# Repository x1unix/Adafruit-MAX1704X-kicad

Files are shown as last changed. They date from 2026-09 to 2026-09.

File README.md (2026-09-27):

# Adafruit MAX17048 LiPoly / LiIon Fuel Gauge — KiCad port

A **KiCad 10 conversion of Adafruit's original EagleCAD project** for the MAX17048
LiPoly / LiIon Fuel Gauge and Battery Monitor breakout (STEMMA QT form factor).

This repository contains **only the converted design**. It is not an Adafruit product
and is not maintained by Adafruit.

## Upstream

| | |
|---|---|
| Original project | <https://github.com/adafruit/Adafruit-MAX17048-PCB> |
| Product page | <https://www.adafruit.com/product/5580> |
| Converted from commit | `cc7d6e2` — *"Adding cookiecutter output"*, 2022-08-31 |
| Source format | EagleCAD 9.6.2 (`.sch` + `.brd`) |
| Designed by | Limor Fried / Ladyada for Adafruit Industries |

## Board

| | |
|---|---|
| Fuel gauge IC | **MAX17048G+T10** — TDFN-8, 2 x 2 mm, 0.5 mm pitch (package outline 21-0168) |
| Size | 25.40 x 20.32 mm (1.00 x 0.80 in) |
| Stackup | 2 layer |
| Interface | I2C, two STEMMA QT / Qwiic connectors (JST SH 4-pin) |
| Battery | Two JST PH 2-pin ports |
| Converted with | KiCad 10.0.5 |

`MAX17048G+T10` decodes as: `MAX17048` 1-cell ModelGauge fuel gauge, `G` TDFN package,
`+` lead-free, `T10` tape and reel. The I2C address is fixed at **`0x36`** (7-bit).

Datasheet: [`docs/max17048-max17049.pdf`](docs/max17048-max17049.pdf), with a condensed
markdown version at [`docs/max17048-datasheet.md`](docs/max17048-datasheet.md).

## Opening it

Open `Adafruit-MAX17048-STEMMA.kicad_pro` in KiCad 10.0.5 or newer.

Footprints are stored **inline in the `.kicad_pcb`**, and symbols live in the
project-local `Adafruit-MAX17048-STEMMA-eagle-import.kicad_sym`. There are no external
library dependencies — the project opens standalone.

## Deviations from upstream

One intentional change. Everything else is a faithful conversion.

- **MAX17048 symbol pin labels corrected.** Adafruit's Eagle symbol had `SCL` and `SDA`
  transposed, compensated by deliberately crossed net wiring. The labels now match the
  datasheet. **The netlist is byte-identical to upstream** — this is purely cosmetic.
  Full explanation: [`docs/max17048-symbol.md`](docs/max17048-symbol.md).

3D models were not inherited — the Eagle source contained none. The MAX17048 model has
since been added; the remaining parts still have empty 3D slots. See
[`docs/3d-models.md`](docs/3d-models.md).

## Documentation

| Document | Contents |
|---|---|
| [`docs/max17048-datasheet.md`](docs/max17048-datasheet.md) | Condensed MAX17048 datasheet — pinout, I2C address, registers, electrical limits |
| [`docs/conversion.md`](docs/conversion.md) | How the conversion was performed, and what the importer did or didn't carry over |
| [`docs/max17048-symbol.md`](docs/max17048-symbol.md) | The upstream SCL/SDA pin-label defect and why the board is still correct |
| [`docs/footprints.md`](docs/footprints.md) | Footprint provenance and the real manufacturer part behind each one |
| [`docs/3d-models.md`](docs/3d-models.md) | 3D model status, stock matches, and what needs downloading |
| [`docs/known-issues.md`](docs/known-issues.md) | DRC/ERC output, and which findings are false positives |

## License

The original design is released by Adafruit under
**Creative Commons Attribution-ShareAlike 3.0 Unported** — full text in
[`license.txt`](license.txt), copied verbatim from upstream. This conversion inherits
that license.

> Adafruit invests time and resources providing this open source design, please support
> Adafruit and open-source hardware by purchasing products from
> [Adafruit](https://www.adafruit.com)!
>
> Designed by Limor Fried/Ladyada for Adafruit Industries.
>
> Creative Commons Attribution/Share-Alike, all text above must be included in any
> redistribution.

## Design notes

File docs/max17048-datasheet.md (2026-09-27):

# MAX17048 — datasheet reference

Machine-readable condensation of [`max17048-max17049.pdf`](max17048-max17049.pdf)
(Maxim/Analog Devices doc `19-6171 Rev 7, 11/16`), scoped to what matters for this board.

**The PDF is authoritative.** This file exists so agents don't have to parse 19 pages of
images. Anything safety- or tolerance-critical should be confirmed against the PDF.

## Identity

| | |
|---|---|
| Part on this board | **MAX17048G+T10** |
| Function | 3µA 1-cell Li+ fuel gauge with ModelGauge |
| Package | 8 TDFN-EP, 2 x 2 mm, 0.5 mm pitch, 0.8 mm height |
| Package code | `T822+3` |
| Package outline | `21-0168` |
| Land pattern | `90-0065` |
| Temp range | -40°C to +85°C |
| Suffix decode | `G` = TDFN, `+` = lead-free/RoHS, `T10` = tape and reel |

`MAX17048` is the 1-cell part; `MAX17049` is the 2-cell variant sharing the same
datasheet, pinout and registers. **This board uses the 1-cell MAX17048.**

> Note: Adafruit's Eagle package description cites outline `21-0268`. The datasheet's
> Package Information table gives `21-0168` for 8 TDFN-EP. Use `21-0168`.

## Pinout — TDFN-8

```
[ 1 ] CTG      SDA [ 8 ]
[ 2 ] CELL     SCL [ 7 ]
[ 3 ] VDD    QSTRT [ 6 ]
[ 4 ] GND     ALRT [ 5 ]
              [ EP ]
```

| Pin | Name | Function |
|---|---|---|
| 1 | CTG | Connect to ground. |
| 2 | CELL | Connect to positive battery terminal. **MAX17048: not internally connected.** MAX17049: voltage sense input. |
| 3 | VDD | Power-supply input, bypass 0.1µF to GND. **MAX17048: this is the voltage sense input** — connect to positive battery terminal. |
| 4 | GND | Ground, connect to negative battery terminal. |
| 5 | ALRT | Open-drain, active-low alert output. Optionally to host interrupt. |
| 6 | QSTRT | Quick-start input, hardware reset. **Connect to GND if unused.** |
| 7 | SCL | I2C clock input. Internal pulldown for disconnect sensing. |
| 8 | SDA | Open-drain I2C data I/O. Internal pulldown for disconnect sensing. |
| — | EP | Exposed pad (TDFN only). Connect to GND. |

Note that on the **MAX17048**, `VDD` — not `CELL` — is what gets measured.

### As wired on this board

| Pin | Name | Net |
|---|---|---|
| 1 | CTG | `GND` |
| 2 | CELL | `VBAT` |
| 3 | VDD | `VDD` (fed via solder jumper SJ2) |
| 4 | GND | `GND` |
| 5 | ALRT | `INT` — broken out to JP1.5 |
| 6 | QSTRT | `QSTART` — broken out to JP1.6, **not tied to GND** |
| 7 | SCL | `SCL` |
| 8 | SDA | `SDA` |
| EP | — | `GND` |

Closest datasheet configuration (Table 3): *1S host-side location, low-cell interrupt*.

> The symbol in this project had `SCL`/`SDA` labels transposed upstream. Corrected —
> see [`max17048-symbol.md`](max17048-symbol.md) before touching anything I2C.

## I2C

| | |
|---|---|
| 7-bit address | **`0x36`** — fixed, not configurable |
| 8-bit address | `0x6C` write / `0x6D` read |
| Max clock | 400 kHz (works at any speed from 0) |
| Register width | **All registers are 16-bit.** 8-bit writes have no effect. |
| Byte order | MSB first; MSB of a 16-bit register lives at the even address |

Use `0x36` with Linux/Arduino/CircuitPython APIs, which take 7-bit addresses. The
datasheet quotes the 8-bit form, which is a common source of confusion.

Address auto-increments across a multi-byte transaction. Writes beyond `0x4F` are
ignored; reads beyond `0xFF` return `0xFF`.

## Registers

| Addr | Name | R/W | LSb | Default | Purpose |
|---|---|---|---|---|---|
| `0x02` | VCELL | R | 78.125 µV/cell | — | ADC measurement of VCELL |
| `0x04` | SOC | R | 1%/256 | — | Battery state of charge |
| `0x06` | MODE | W | — | `0x0000` | Quick-start, hibernate status, sleep enable |
| `0x08` | VERSION | R | — | `0x001_` | IC production version |
| `0x0A` | HIBRT | R/W | — | `0x8030` | Hibernate entry/exit thresholds |
| `0x0C` | CONFIG | R/W | — | `0x971C` | RCOMP, sleep, alert config |
| `0x14` | VALRT | R/W | 20 mV | `0x00FF` | Voltage alert min/max |
| `0x16` | CRATE | R | 0.208 %/hr | — | Approximate charge/discharge rate |
| `0x18` | VRESET/ID | R/W | 40 mV | `0x96__` | Reset threshold + factory ID |
| `0x1A` | STATUS | R/W | — | `0x01__` | Alert cause flags |
| `0x40`–`0x7F` | TABLE | W | — | — | Custom battery model |
| `0xFE` | CMD | R/W | — | `0xFFFF` | POR command |

### Bit layouts

**MODE (`0x06`)** — MSB: `X | QuickStart | EnSleep | HibStat | X X X X`, LSB all don't-care.

**CONFIG (`0x0C`)** — MSB `RCOMP[7:0]` (default `0x97`); LSB `SLEEP | ALSC | ALRT | ATHD[4:0]`.
- `RCOMP` — temperature compensation. Host should update at least once per minute:
  ```
  if (T > 20) RCOMP = 0x97 + (T - 20) * (-0.5);
  else        RCOMP = 0x97 + (T - 20) * (-5.0);
  ```
- `ATHD` — empty alert threshold, `(32 - ATHD)%`, range 1–32%. POR `0x1C` = 4%.
- `ALSC` — enable alert on 1% SOC change.
- `ALRT` — alert status; **write 0 to clear**, which also deasserts the ALRT pin.

**STATUS (`0x1A`)** — MSB `X | EnVR | SC | HD | VR | VL | VH | RI`.
`RI` reset indicator, `VH`/`VL` voltage high/low, `VR` voltage reset, `HD` SOC low,
`SC` 1% SOC change. Clear the bit after servicing.

**HIBRT (`0x0A`)** — MSB `HibThr` (0.208 %/hr), LSB `ActThr` (1.25 mV).
`0x0000` disables hibernate, `0xFFFF` forces it always on.

**VALRT (`0x14`)** — MSB `VALRT.MIN`, LSB `VALRT.MAX`, both 20 mV/LSb.

**VRESET/ID (`0x18`)** — MSB `VRESET[7:1]` (40 mV/LSb) + `Dis` bit 0; LSB is the
read-only factory `ID`. For removable batteries set at least 300 mV below empty
voltage; for captive batteries set to 2.5 V.

**CMD (`0xFE`)** — write `0x5400` for a full POR.

**TABLE unlock** — write `0x57` to `0x3F` and `0x4A` to `0x3E`. ModelGauge registers do
not update while unlocked, so relock promptly with `0x00` to both.

## Electrical

| Parameter | Min | Typ | Max | Unit |
|---|---|---|---|---|
| VDD supply voltage | 2.5 | | 4.5 | V |
| Supply current, sleep (TA ≤ +50°C) | | 0.5 | 2 | µA |
| Supply current, hibernate (reset comp disabled) | | 3 | 5 | µA |
| Supply current, hibernate (reset comp enabled) | | 4 | | µA |
| Supply current, active | | 23 | 40 | µA |
| Voltage error (VCELL 3.6 V, +25°C) | -7.5 | | +7.5 | mV/cell |
| Voltage-measurement resolution | | 1.25 | | mV/cell |
| Voltage-measurement range (MAX17048, VDD pin) | 2.5 | | 5 | V |
| VRESET configurable range (40 mV steps) | 2.28 | | 3.48 | V |
| VRESET trimmed at 3 V | 2.85 | 3.0 | 3.15 | V |
| ADC sample period, active | | 250 | | ms |
| ADC sample period, hibernate | | 45 | | s |
| SCL clock frequency | 0 | | 400 | kHz |
| VIH (SDA, SCL, QSTRT) | 1.4 | | | V |
| VIL (SDA, SCL, QSTRT) | | | 0.5 | V |
| VOL (SDA, ALRT) at IOL = 4 mA | | | 0.4 | V |
| Bus low-detection timeout | 1.75 | | 2.5 | s |

### Absolute maximum ratings

| | |
|---|---|
| CELL to GND | -0.3 V to +12 V |
| All other pins to GND | -0.3 V to +6 V |
| Continuous sink current, SDA / ALRT | 20 mA |
| Operating temperature | -40°C to +85°C |
| Storage temperature | -55°C to +125°C |
| Reflow soldering | +260°C |
| Lead temperature (TDFN, soldering 10s) | +300°C |

## Behaviour worth knowing

- **ModelGauge needs no current-sense resistor** and does not accumulate error the way
  coulomb counters do. No periodic correction events required.
- **Battery insertion:** OCV is ready 17 ms after insertion, SOC 175 ms after that.
  First SOC update is roughly 1 s after POR.
- **Quick-start should usually not be used.** The IC handles insertion transparently.
  Only use it when the power-up sequence is noisy enough to spoil the initial SOC
  estimate, and only when VCELL is fully relaxed. POR includes a quick-start.
- **Hibernate is automatic by default** and is the recommended configuration. The IC
  drops to a 45 s ADC period below C/4 loading, cutting quiescent current under 5 µA
  without hurting accuracy.
- **Sleep mode** (< 1 µA) halts everything — the IC cannot detect self-discharge, so
  wake it before charging or discharging. Enter with `MODE.EnSleep = 1` plus either
  `CONFIG.SLEEP = 1` or holding SDA and SCL low past `tSLEEP`. Prefer hibernate if
  4 µA is tolerable.
- **Alerts** are level-driven: ALRT stays low until software writes `CONFIG.ALRT = 0`.
  Five sources — low SOC, 1% SOC change, reset, overvoltage, undervoltage.
- **Instantaneous voltage does not map to SOC.** One VCELL value can correspond to many
  SOC values (3.81 V occurs at 2%, 50% and 72% in the datasheet example). Don't
  reimplement SOC from voltage.

## Pull-ups

The IC provides none. The system must supply pull-ups on SDA, SCL and ALRT (if used).
On this board that is the `RESPACK_4X0603` array (R3, 10K).

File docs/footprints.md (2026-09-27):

# Footprint provenance

All footprints are **Adafruit's originals**, carried over from the Eagle `.brd` and
stored inline in `Adafruit-MAX17048-STEMMA.kicad_pcb`.

**Do not swap these for KiCad-official footprints.** Adafruit's pads deliberately
differ — oversized JST mounting tabs, 0.9 mm outer pitch on the resistor array, longer
JST PH pin pads. Substituting stock footprints would change the board.

## Real parts behind each footprint

Identified by comparing pad geometry against the KiCad-official library. Eagle stores
pad rotation separately (`rot="R90"`), which has to be applied before comparing.

| Ref | Eagle footprint | Actual part | Match quality |
|---|---|---|---|
| X3 | `TDFN8_2X2MM` | **MAX17048G+T10**, TDFN-8 2x2 mm, 0.5 mm pitch, EP 0.8 x 1.38 mm (package outline 21-0168) | KiCad equivalent: `TDFN-8-1EP_2x2mm_P0.5mm_EP0.8x1.2mm` |
| CONN3, CONN4 | `JST_SH4` | **JST SM04B-SRSS-TB**, SH series 1.0 mm, 4-pin, side-entry SMT (STEMMA QT / Qwiic) | Exact match to KiCad-official: 0.6 x 1.55 pins at 1 mm pitch, 1.2 x 1.8 tabs |
| X1, X2 | `JSTPH2_BATT` | **JST S2B-PH-SM4-TB**, PH series 2.0 mm, 2-pin, side-entry SMT with tabs | Same part; Adafruit uses longer pin pads (4.6 vs 3.5 mm) and larger tabs |
| R3 | `RESPACK_4X0603` | 4 x 0603 convex resistor array, 10K | Near-match to `R_Array_Convex_4x0603`; Adafruit's outer pads sit at 0.9 mm, stock is 0.8 mm, and the array runs along X rather than Y |
| C1, C2 | `0603-NO` | 1uF 0603 MLCC | Standard 0603 |
| R2 | `0603-NO` | 10K 0603 | Standard 0603 |
| D1 | `CHIPLED_0603_NOOUTLINE` | Green 0603 LED | Standard 0603 |
| JP1 | `1X06_ROUND_70` | 1x6 2.54 mm THT header | 1 mm drill, 1.778 mm pad |
| JP2 | `1X02_ROUND` | 1x2 2.54 mm THT header | 1 mm drill, 1.778 mm pad |
| SJ1 | `SOLDERJUMPER_CLOSEDWIRE` | Solder jumper, normally closed | The `WIRE` pad intentionally bridges pads 1 and 2 |
| SJ2 | `SOLDERJUMPER_2WAY_OPEN_NOPASTE` | 3-pad 2-way solder jumper | |
| U$19, U$21 | `MOUNTINGHOLE_2.5_PLATED` | 2.5 mm plated mounting hole, 3.2 mm pad | |
| FID3, FID4 | `FIDUCIAL_1MM` | 1 mm fiducial | |
| U$22 | `ADAFRUIT_3.5MM` | Adafruit logo, silkscreen only | |
| U$25 | `PCBFEAT-REV-040` | Revision marker, silkscreen only (`${REV}` = 040) | |
| U$30, U$31 | `STEMMAQT` | STEMMA QT label, silkscreen only | |
| UNK_HOLE_0/1 | — | Eagle free holes, 2.54 mm NPTH — not components | |

## Connector pinouts

STEMMA QT / Qwiic (`JST_SH4`), matching the standard:

```
1 = GND    2 = V+ (VCC)    3 = SDA    4 = SCL
```

Both CONN3 and CONN4 are wired in parallel, as pass-through I2C ports.

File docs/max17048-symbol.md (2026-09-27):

# The MAX17048 SCL/SDA pin-label defect

**Summary: Adafruit's Eagle symbol labels SCL and SDA backwards, and the schematic
wiring compensates. The copper is correct. Do not "fix" this by rewiring.**

## The datasheet

`MAX17048G+T10`, TDFN-8 2 x 2 mm (package outline 21-0168):

```
[ 1 ] CTG      SDA [ 8 ]
[ 2 ] CELL     SCL [ 7 ]
[ 3 ] VDD    QSTRT [ 6 ]
[ 4 ] GND     ALRT [ 5 ]
                  [ EP ] thermal pad
```

Pin 7 is SCL. Pin 8 is SDA. (`docs/max17048-max17049.pdf`, Pin Configuration.)

## Error 1 — the symbol

In Adafruit's `adafruit_sensor` Eagle library, `MAX17048/T` maps pin *names* to pads
like this:

```
SCL   -> pad 8      (datasheet says pad 8 is SDA)
SDA   -> pad 7      (datasheet says pad 7 is SCL)
VDD   -> pad 3      CELL  -> pad 2
!ALRT -> pad 5      QSTRT -> pad 6
VSS   -> pads 1, 4, THERMAL
```

Both I2C labels are transposed.

## Error 2 — the wiring, which cancels it

The schematic then connects the nets to the *wrong-looking* pins, on purpose:

```
net SCL  ->  symbol pin "SDA"  ->  pad 7   = SCL   correct
net SDA  ->  symbol pin "SCL"  ->  pad 8   = SDA   correct
```

The Eagle board file confirms the signals land on the right copper:

```
net SDA -> CONN3.3, X3.8
net SCL -> CONN3.4, X3.7
```

That also matches the STEMMA QT / Qwiic standard (1 = GND, 2 = V+, 3 = SDA, 4 = SCL),
so the whole signal chain is sound. This is why the shipping product works.

## What was changed in this port

Only the two pin **names** on `MAX17048/T`, in both places KiCad stores a symbol:

- `Adafruit-MAX17048-STEMMA-eagle-import.kicad_sym` (the project library)
- the `lib_symbols` cache embedded in `Adafruit-MAX17048-STEMMA.kicad_sch`

Both are required — the schematic embeds its own copy of every symbol, and that copy is
what the canvas renders. Editing one alone leaves the two out of sync, which ERC reports
as `lib_symbol_issues`.

No wires were touched. Wires attach to pin positions and numbers, not names, so net
`SCL` stayed on pin 7 and simply reads correctly now. The `.kicad_pcb` was not modified.

### Verification

Exporting the full `(ref, pin)` mapping for every net before and after gave an
identical result:

```
FULL netlist identical before vs after?  YES - electrically unchanged
```

Resulting X3 assignment, every pin matching the datasheet:

```
net SCL    -> pin 7        name=SCL_7         datasheet=SCL
net SDA    -> pin 8        name=SDA_8         datasheet=SDA
net VDD    -> pin 3        name=VDD_3         datasheet=VDD
net VBAT   -> pin 2        name=CELL_2        datasheet=CELL
net INT    -> pin 5        name=~{ALRT}_5     datasheet=ALRT
net QSTART -> pin 6        name=QSTRT_6       datasheet=QSTRT
net GND    -> pins 1, 4, THERMAL              CTG + GND + EP
```

Reproduce with:

```sh
kicad-cli sch export netlist --format kicadxml \
  -o /tmp/net.xml Adafruit-MAX17048-STEMMA.kicad_sch
```

## Related non-issues

- **There is no `CTG` pin on the symbol.** The datasheet defines pin 1 as CTG,
  "connect to ground", so Adafruit folded it into `VSS`.
- **`VSS` shows no single pin number** because it carries three pads — 1, 4 and
  THERMAL. KiCad imports that as stacked pins; all three are present in the netlist.

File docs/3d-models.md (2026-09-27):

# 3D models

**Status: 1 of 9 attached.** X3 (the MAX17048) has a model; the rest still have empty
3D slots.

This is deliberate, not an oversight. The Eagle source contains **zero 3D data** — no
`<package3d>` elements, no `packages3d` section, no STEP references. Eagle 9.6.2 kept
3D packages in Autodesk-managed cloud libraries, and Adafruit's published files carry
only `urn:adsk.eagle:` handles for two symbols. Nothing was lost in conversion; there
was nothing to inherit.

Models can be attached at any time without redoing the import.

## Attached

### X3 — MAX17048G+T10

`3dmodels/MAX17048G-T10--3DModel-STEP-510211.STEP` — AP214 STEP exported from
SolidWorks 2021, internally named `MAX17048G+T10.STEP`. Geometry verified at
2.000 x 2.000 x 0.800 mm, matching the TDFN-8 2 x 2 mm body.

Attached to the `TDFN8_2X2MM` footprint in `Adafruit-MAX17048-STEMMA.kicad_pcb` as:

```
(model "${KIPRJMOD}/3dmodels/MAX17048G-T10--3DModel-STEP-510211.STEP"
    (offset (xyz 0 0 0))
    (scale  (xyz 1 1 1))
    (rotate (xyz -90 0 0))
)
```

**The -90 degree X rotation is required.** The source model is authored **Y-up** — the
2 x 2 mm body lies in the X-Z plane with height running along +Y from 0 to 0.8 mm.
KiCad expects Z-up, with the part sitting on the board at Z = 0. Models exported from
SolidWorks and 3D ContentCentral commonly have this convention; check the axis extents
before assuming a model drops in at zero rotation.

Verified by rendering: body centred in the silkscreen outline, all 8 leads landing on
their pads, pin-1 dot over pad 1.

```sh
kicad-cli pcb render --side top --zoom 3.4 --pivot '0,-0.165,0' \
  --quality high -o /tmp/x3.png Adafruit-MAX17048-STEMMA.kicad_pcb
```

## Where to put them

Project-local, so they survive KiCad upgrades and travel with the repository:

```
3dmodels/
```

Reference them from each footprint's 3D tab as:

```
${KIPRJMOD}/3dmodels/<file>.step
```

## Still needs downloading — 1 part

Ships with a KiCad **footprint** but no STEP file. Verified absent across all 7245
stock models in KiCad 10.0.5.

### X1, X2 — JST S2B-PH-SM4-TB

PH series, 2 mm pitch, 2-pin, side-entry SMT with mounting tabs.
KiCad ships `JST_PH_S2B-PH-SM4-TB_1x02-1MP_P2.00mm_Horizontal.kicad_mod` but not the
`.step`. Only the through-hole variants have models (`B2B-PH-K`, `S2B-PH-K`).

- [SnapMagic Search](https://www.snapeda.com/parts/S2B-PH-SM4-TB/JST%20Sales%20America%20Inc./view-part/)
- [Ultra Librarian](https://app.ultralibrarian.com/details/c0ea14ac-1ee6-11e9-ab3a-0a3560a4cccc/JST/S2B-PH-SM4-TB-LF-SN-)
- [Digi-Key](https://www.digikey.com/en/models/926655)
- [3D ContentCentral](https://www.3dcontentcentral.com/download-model.aspx?catalogid=171&id=817113)

## Available in stock — 7 parts

Paths relative to `${KICAD10_3DMODEL_DIR}`.

| Ref | Model | Fit |
|---|---|---|
| C1, C2 | `Capacitor_SMD.3dshapes/C_0603_1608Metric.step` | exact |
| R2 | `Resistor_SMD.3dshapes/R_0603_1608Metric.step` | exact |
| D1 | `LED_SMD.3dshapes/LED_0603_1608Metric.step` | exact |
| JP1 | `Connector_PinHeader_2.54mm.3dshapes/PinHeader_1x06_P2.54mm_Vertical.step` | exact |
| JP2 | `Connector_PinHeader_2.54mm.3dshapes/PinHeader_1x02_P2.54mm_Vertical.step` | exact |
| CONN3, CONN4 | `Connector_JST.3dshapes/JST_SH_SM04B-SRSS-TB_1x04-1MP_P1.00mm_Horizontal.step` | pad geometry identical to KiCad-official, but the footprint origin differs by ~0.5 mm in Y — nudge in the 3D viewer |
| R3 | `Resistor_SMD.3dshapes/R_Array_Convex_4x0603.step` | approximate — needs a **90 degree Z rotation** (Adafruit's array runs along X, the model along Y), and Adafruit's outer pads are 0.9 mm vs the model's 0.8 mm |

For an exact R3, download a 4x0603 array model (Panasonic EXB-38V, Yageo YC164) instead.

## Needs no model

Mechanical or artwork only: `SJ1`, `SJ2` (solder jumpers, copper only), `FID3`, `FID4`
(fiducials), `U$19`, `U$21` (bare plated mounting holes), `U$22` (Adafruit logo),
`U$25` (rev marker), `U$30`, `U$31` (STEMMA QT silkscreen), `UNK_HOLE_0/1` (free holes).

## Note on sourcing

There is **no official Adafruit KiCad library** — Adafruit publishes Eagle libraries
only. Don't spend time looking for one.

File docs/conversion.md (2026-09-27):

# How this conversion was performed

Source: Adafruit's EagleCAD 9.6.2 project, commit `cc7d6e2` (2022-08-31).
Target: KiCad 10.0.5.

## Why the GUI was required

KiCad exposes its **board** importers to the command line but not its **schematic**
importers:

- `kicad-cli pcb import` — converts Eagle / Altium / PADS / CADSTAR / pcad boards headlessly.
- `kicad-cli sch` — offers only `erc`, `export`, `upgrade`. There is **no** `import`.

There is no standalone `eeschema` binary on macOS either; the editors ship as separate
`.app` bundles with no CLI entry point.

So the schematic had to go through the GUI, and doing the whole project there is
preferable anyway — a full project import links symbols to footprints, so the board
netlist is cross-referenced to the schematic. A CLI board-only import gives you nets
but no schematic association.

```
File -> Import Non-KiCad Project -> Import EAGLE Project...
```

Select the `.sch`; the matching `.brd` is picked up automatically from the same
basename and folder.

## What carried over cleanly

Eagle `.sch`/`.brd` files are **self-contained** — every footprint and symbol
definition is embedded in the file itself. All 16 packages used by the board were
present, with zero used-but-undefined packages, so no external library had to be
installed before converting.

Import statistics:

| | |
|---|---|
| Footprints | 24 |
| Tracks | 126 |
| Vias | 13 |
| Zones | 6 |
| Pads | 65 |
| Nets | 11 — GND, VCC, VDD, VBAT, SCL, SDA, INT, QSTART, N$1, N$2, N$4 |

Footprints are written **inline into the `.kicad_pcb`**, so the geometry is Adafruit's
original and the board needs no `fp-lib-table`. Symbols went into the project-local
`Adafruit-MAX17048-STEMMA-eagle-import.kicad_sym`, registered via `sym-lib-table`.

## What did not carry over

- **Design rules and net classes.** Board Setup starts at KiCad defaults. Upstream used
  looser clearances than KiCad's defaults — see [`known-issues.md`](known-issues.md).
- **3D models.** The Eagle project contained none to begin with. See
  [`3d-models.md`](3d-models.md).
- **Eagle-specific layers** needed review: `tRestrict`/`bRestrict`, `tKeepout`,
  `tGlue`, `Measures`, `tDocu`. The GUI importer resolved these; a raw
  `kicad-cli pcb import` instead leaves items on an `UNDEFINED` layer, which makes the
  board unloadable until remapped (`Measures` dimensions belong on `Dwgs.User`,
  keepout graphics on a `User.n` layer).

## Import artifacts

- **`UNK_HOLE_0` / `UNK_HOLE_1`** at (2.54, 17.78) and (22.86, 17.78) are Eagle *free
  holes* (`<hole drill="2.54">`), not components. The importer wraps each bare NPTH in
  a dummy footprint, so they appear as unannotated parts.
- **`${REV}` text variable** on the `PCBFEAT-REV-040` rev marker (U$25) is unresolved
  unless defined. It is set to `040` in `Adafruit-MAX17048-STEMMA.kicad_pro`, taken
  from the Eagle package name.

## Verification commands

```sh
# board loads, and DRC
kicad-cli pcb drc --format json -o /tmp/drc.json Adafruit-MAX17048-STEMMA.kicad_pcb

# schematic ERC
kicad-cli sch erc --format json -o /tmp/erc.json Adafruit-MAX17048-STEMMA.kicad_sch

# netlist, for comparing against the Eagle source
kicad-cli sch export netlist --format kicadxml -o /tmp/net.xml Adafruit-MAX17048-STEMMA.kicad_sch

# visual check
kicad-cli pcb render --side top -o /tmp/top.png Adafruit-MAX17048-STEMMA.kicad_pcb

# symbol library parses
kicad-cli sym export svg -o /tmp/syms Adafruit-MAX17048-STEMMA-eagle-import.kicad_sym
```

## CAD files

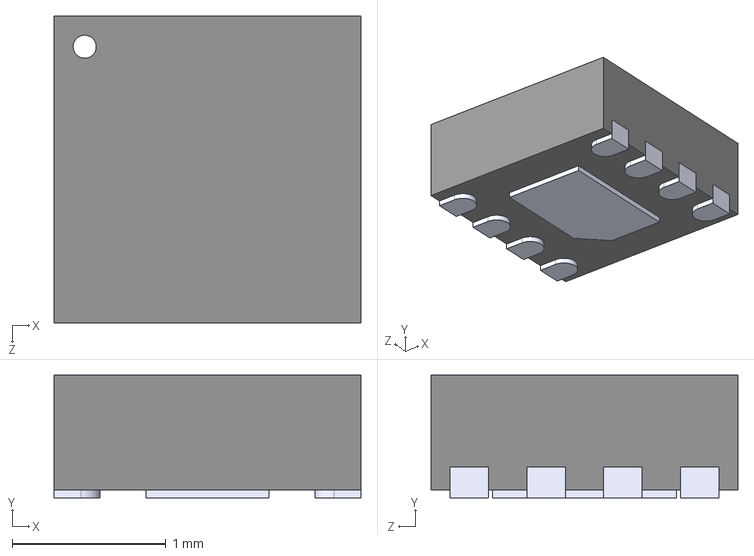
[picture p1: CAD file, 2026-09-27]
3dmodels/MAX17048G-T10--3DModel-STEP-510211.STEP
2.00 x 0.8 x 2.00 mm

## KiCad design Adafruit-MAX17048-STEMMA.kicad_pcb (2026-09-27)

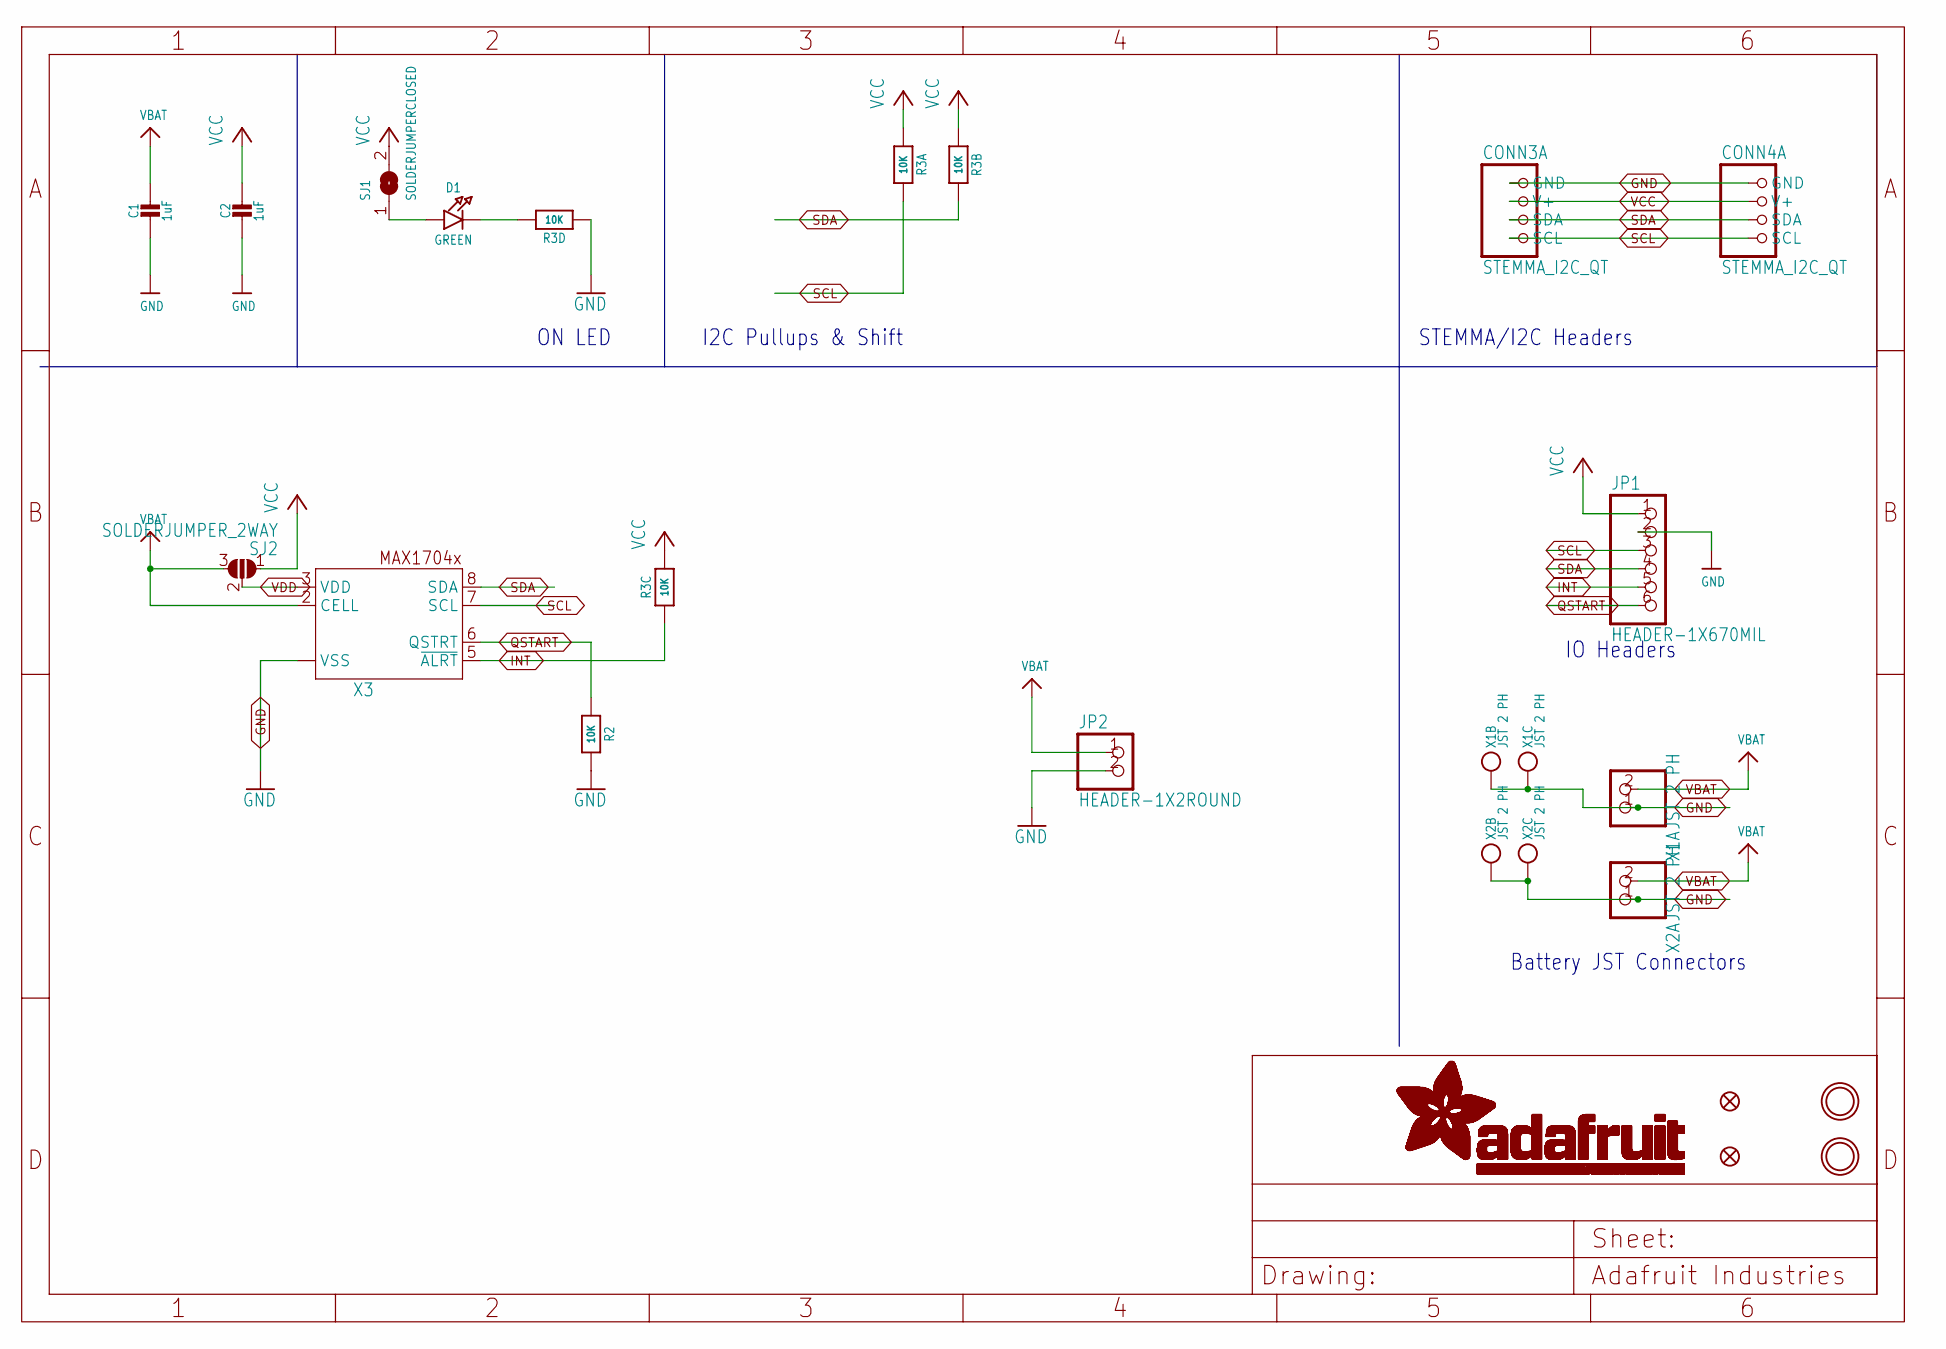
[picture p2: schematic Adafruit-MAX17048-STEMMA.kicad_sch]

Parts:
C1, C2: 1uF; 0603-NO
CONN3, CONN4: STEMMA_I2C_QT; JST_SH4
D1: GREEN; CHIPLED_0603_NOOUTLINE
FID3, FID4: FIDUCIAL_1MM
JP1: HEADER-1X670MIL; 1X06_ROUND_70
JP2: HEADER-1X2ROUND; 1X02_ROUND
R2: 10K; 0603-NO
R3: 10K; RESPACK_4X0603
SJ1: SOLDERJUMPERCLOSED; SOLDERJUMPER_CLOSEDWIRE
SJ2: SOLDERJUMPER_2WAY; SOLDERJUMPER_2WAY_OPEN_NOPASTE
U$19, U$21: MOUNTINGHOLE2.5; MOUNTINGHOLE_2.5_PLATED
X1, X2: JST 2 PH; JSTPH2_BATT
X3: MAX17048/T; TDFN8_2X2MM

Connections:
GND: C1.2, C2.2, CONN3.1 (GND), CONN4.1 (GND), JP1.2, JP2.2, R2.2, R3.4 (1), X1.1, X1.NC1, X1.NC2, X2.1, X2.NC1, X2.NC2, X3.1 (VSS), X3.4 (VSS), X3.THERMAL (VSS)
INT: JP1.5, R3.3 (1), X3.5 (~ALRT)
unnamed: D1.C, R3.5 (2)
unnamed: D1.A, SJ1.1
QSTART: JP1.6, R2.1, X3.6 (QSTRT)
SCL: CONN3.4 (SCL), CONN4.4 (SCL), JP1.3, R3.8 (2), X3.7 (SCL)
SDA: CONN3.3 (SDA), CONN4.3 (SDA), JP1.4, R3.7 (2), X3.8 (SDA)
VBAT: C1.1, JP2.1, SJ2.3, X1.2, X2.2, X3.2 (CELL)
VCC: C2.1, CONN3.2 (V+), CONN4.2 (V+), JP1.1, R3.1, R3.2 (1), R3.6 (2), SJ1.2, SJ2.1
VDD: SJ2.2, X3.3 (VDD)

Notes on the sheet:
I2C Pullups & Shift
STEMMA/I2C Headers
ON LED
IO Headers
Battery JST Connectors

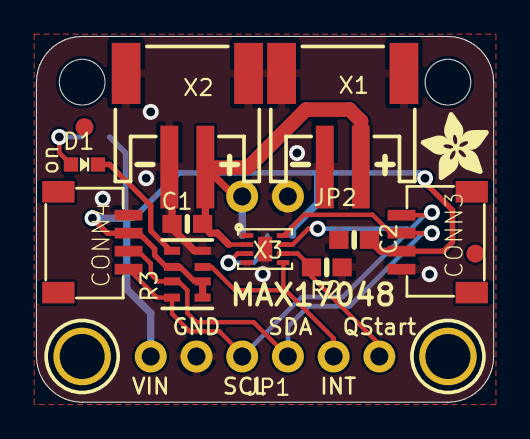
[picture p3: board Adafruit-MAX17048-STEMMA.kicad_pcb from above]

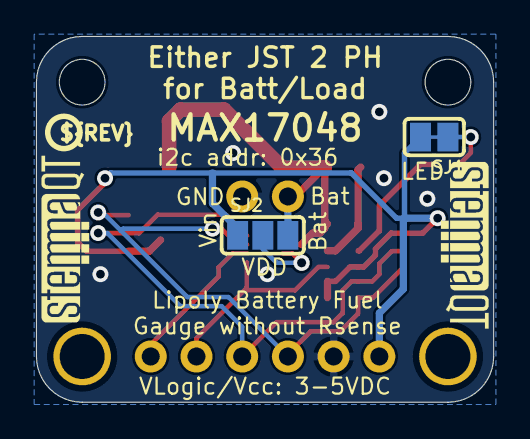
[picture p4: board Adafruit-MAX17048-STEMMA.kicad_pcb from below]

Board: 2 copper layers, 25.4 x 20.3 mm, 24 parts (5 on the bottom side), 10 nets.

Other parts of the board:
U$22: ADAFRUIT_3.5MM
U$25: PCBFEAT-REV-040
U$30, U$31: STEMMAQT
UNK_HOLE_0: dummyfp0
UNK_HOLE_1: dummyfp1

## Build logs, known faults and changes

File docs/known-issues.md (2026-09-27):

# Known issues and false positives

Both DRC and ERC report violations on this design. **Most are artifacts of the
conversion or of upstream design choices, not defects.** This document separates them
so nobody "fixes" a working board.

## DRC — 96 violations, 1 unconnected

Measured on the GUI-imported board with zones filled and KiCad default rules.

### Not bugs

| Finding | Count | Why |
|---|---|---|
| `silk_overlap`, `silk_over_copper` | 68 | Eagle tolerated silkscreen over pads; KiCad's defaults do not. Upstream shipped this way. |
| `solder_mask_bridge` | 18 | Fine-pitch parts against KiCad's default mask rules. |
| `clearance` on SJ1 (pad 1 / WIRE, pad 2 / WIRE) | 2 | **The solder jumper working as designed.** `SOLDERJUMPER_CLOSEDWIRE` has a netless `WIRE` pad that deliberately bridges pads 1 and 2 — that is what makes it normally-closed. See *Solder jumpers* below. |
| `items_not_allowed` | 2 | The mounting-hole pads sitting inside their own imported keepout. |
| `text_thickness`, `text_height` | 4 | Silkscreen text below KiCad's default minimums. |

### Worth attention

- **1 unconnected: an isolated GND island on F.Cu.** The top-layer GND pour fills as
  three islands. Two are properly stitched; the third (~2.33 mm², roughly
  X 150.4–154.6, Y 105.1–107.2, between X3 and CONN3) contains **no GND via and no GND
  pad**, so it is floating copper.

  **A stitching via does not fit.** The island is 4.21 x 2.09 mm but narrow — the
  largest via pad that clears all neighbouring copper by the board minimum (0.2032 mm)
  is **0.496 mm diameter**, at (151.06, 106.36). The board's standard via is 0.889 mm
  pad / 0.4826 mm drill, and even a 0.5 mm pad / 0.25 mm drill fails. A via small enough
  would need a sub-0.2 mm drill. Don't retry this.

  Remaining options: leave it (harmless floating copper at this size and frequency),
  set the zone's island-removal threshold so KiCad drops sub-area islands on refill, or
  move R2 / reroute to open up room — which changes Adafruit's layout.

- **2 `starved_thermal`.** JP2 pad 2 (GND, B.Cu) and X3 pad 4 (GND, F.Cu) each get one
  thermal spoke where KiCad's default rule wants two. Upstream had no such rule. X3's
  exposed pad is also tied to GND, so that one is immaterial.

- **Design rules and net classes did not carry over.** Board Setup is at KiCad defaults,
  which are *stricter* than what this board was manufactured to. Set real trace/via/
  clearance minimums before using DRC output to judge the layout.

### Fixed

- **Orphan `N$4` copper stub — removed.** In the Eagle source, signal `N$4` had **zero
  contactrefs** and exactly one wire segment: a 0.635 mm dangling stub on B.Cu that
  overlapped SJ2's pad 2 (`VDD`) and ran within 0.076 mm of the `VBAT` trace. It was
  stray copper inherited from upstream, not intentional design. Deleting it cleared the
  `shorting_items` violation and 2 `clearance` violations (4 -> 2, leaving only the two
  SJ1 solder-jumper ones). Total went 106 -> 96; `solder_mask_bridge` also moved 25 ->
  18 in the same edit, which is reproducible but not fully explained — the cleared
  pairs name SJ1/SJ2 mask polygons rather than `N$4` itself.

### Zone fill

Zones must be filled before DRC output means anything. Filling took unconnected items
from 20 to 1 and cleared all 6 `via_dangling` findings. If a checkout shows them
unfilled, press `B` in the PCB editor and re-run DRC before reading anything into the
counts above.

## Solder jumpers

KiCad models solder jumpers perfectly well — it ships 30 footprints in `Jumper.pretty`
(including `SolderJumper-2_P1.3mm_Bridged_*`) and 11 symbols in `Jumper.kicad_sym`
(`SolderJumper_2_Bridged`, `SolderJumper_3_Bridged12`, …). The everyday idiom is the
same as a **0 ohm resistor**: a two-pin part bridging two nets.

The difference is how the bridge is drawn. KiCad's bridged jumpers have **only two
pads** and no copper between them — the short is a solder blob the assembler adds, so
nothing overlaps and DRC stays quiet. Adafruit's Eagle footprint instead adds a **third
netless `WIRE` pad** physically overlapping pads 1 and 2, which KiCad reads as two
zero-clearance violations.

So the noise is a property of *this imported footprint*, not a gap in KiCad. Options:

1. **Leave it.** The violations are cosmetic; the board is correct.
2. **Give the `WIRE` pad a net** so it stops being a foreign object between two pads.
3. **Rebuild SJ1 as a KiCad solder jumper** (`SolderJumper_2_Bridged` +
   `SolderJumper-2_P1.3mm_Bridged_*`) or a 0 ohm resistor. Cleanest long term, but it
   replaces Adafruit's footprint — see [`footprints.md`](footprints.md) before doing it.

## ERC — 39 violations

| Finding | Count | Why |
|---|---|---|
| `footprint_link_issues` | 25 | Symbols' footprint fields don't resolve to a library, because footprints live **inline in the `.kicad_pcb`** and there is no `fp-lib-table`. Harmless unless you want "update PCB from schematic" to work. |
| `power_pin_not_driven` | 4 | No `PWR_FLAG` symbols. Normal for an imported schematic. |
| `unconnected_wire_endpoint` | 6 | Import artifacts. |
| `missing_bidi_pin`, `missing_unit` | 4 | Import artifacts. |

`lib_symbol_issues` should read **0**. A non-zero count means the project
`.kicad_sym` and the `lib_symbols` cache inside the `.kicad_sch` have drifted apart —
see [`max17048-symbol.md`](max17048-symbol.md).

## Things that look wrong but are correct

- **MAX17048 SCL/SDA.** Upstream had the labels transposed with compensating wiring.
  Corrected here, netlist unchanged. Full detail in [`max17048-symbol.md`](max17048-symbol.md).
- **No `CTG` pin on the MAX17048 symbol.** Datasheet pin 1 is "connect to ground";
  Adafruit folded it into `VSS`.
- **`VSS` has no single pin number** — it carries pads 1, 4 and THERMAL as stacked pins.
- **`UNK_HOLE_0` / `UNK_HOLE_1`** are Eagle free holes, not unannotated components.
- **Adafruit's footprints differ from KiCad-official ones.** Intentional. See
  [`footprints.md`](footprints.md).

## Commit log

2026-09-27 import converted files
    [Adafruit-MAX17048-STEMMA.kicad_pcb, Adafruit-MAX17048-STEMMA.kicad_sch]
2026-09-27 add MAX17048 model
    [Adafruit-MAX17048-STEMMA.kicad_pcb, MAX17048G-T10--3DModel-STEP-510211.STEP]
2026-09-27 Add condensed MAX17048 datasheet for agent consumption
    The datasheet ships as a 19-page PDF of scanned tables, which agents
    cannot cheaply read. docs/max17048-datasheet.md distills the parts that
    matter for this board: TDFN-8 pinout with per-pin function, how each pin
    is actually wired here, the fixed 0x36 7-bit I2C address (the datasheet
    quotes the 8-bit 0x6C/0x6D form, a common source of confusion), the full
    register map with bit layouts, and electrical and absolute-maximum
    limits.
    Notes that on the MAX17048 it is VDD, not CELL, that is measured, and
    that QSTRT is broken out here rather than tied to GND.
    The PDF stays authoritative for tolerance-critical values.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
2026-09-27 Update AGENTS.md 3D model status
    X3 now has a model attached, so the blanket 'not attached' note was
    stale. Only the JST S2B-PH-SM4-TB still needs sourcing.
2026-09-27 Correct solder jumper claim and refresh DRC findings
    The doc claimed KiCad has no concept of an Eagle solder jumper. That is
    wrong: KiCad ships 30 jumper footprints and 11 jumper symbols, and the
    everyday idiom is the same as a 0 ohm resistor. The difference is that
    KiCad's bridged jumpers use two pads with no copper between them, while
    Adafruit's Eagle footprint adds a third netless WIRE pad that physically
    overlaps pads 1 and 2. The DRC noise belongs to the imported footprint,
    not to KiCad.
    Also re-measured DRC with zones filled: 115/20 -> 106/1.
    Two findings previously lumped under 'solder jumpers working as designed'
    turn out to be separate, and one is real. Net N$4 has zero contactref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
2026-09-27 Fill copper zones
    Zone fills were empty after the Eagle import, which made DRC's
    connectivity output meaningless. Filling takes unconnected items from 20
    to 1 and clears all 6 via_dangling findings.
    [Adafruit-MAX17048-STEMMA.kicad_pcb]
2026-09-27 Remove orphan N$4 copper stub inherited from upstream
    In the Eagle source, signal N$4 has zero contactrefs and a single wire
    segment: a 0.635 mm dangling stub on B.Cu that overlapped SJ2's VDD pad
    and ran within 0.076 mm of the VBAT trace. It connected nothing, so the
    board worked, but it was stray copper rather than intentional design.
    Clears the shorting_items violation and two clearance violations, leaving
    only the two SJ1 solder-jumper ones. DRC total 106 -> 96.
    [Adafruit-MAX17048-STEMMA.kicad_pcb]
2026-09-27 Document N$4 removal and why the GND island cannot be stitched
    Records that a stitching via does not fit the isolated F.Cu GND island:
    the largest pad clearing all neighbouring copper by the 0.2032 mm board
    minimum is 0.496 mm diameter, against a 0.889 mm standard via. Even a
    0.5 mm pad fails. Noted so nobody retries it.
